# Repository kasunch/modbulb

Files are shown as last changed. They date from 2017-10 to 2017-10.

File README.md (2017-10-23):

# modBulb - A modular light bulb for VLC
modBulb is an open source light bulb with a modular design that can be customized according to application’s requirements.
modBulb allows users to generate baseband signals simply through an MCU or an FPGA where more sophisticated signal processing is required. 
Moreover, modBulb offers the convenience of reprogramming the MCU and FPGA wirelessly to the users. 

modBulb uses an energy efficient switching LED driving circuitry which makes modBulb usable beyond prototyping and research applications.

## Hardware

modBulb hardware consists of three parts:

- Light source i.e. LEDs
- LED driver
- Baseband generator

There are two types of baseband generators:

- MCU baseband generator

  This baseband generator is built with TI's CC3200 SoC which is clocked at 80 MHz.

- FPGA baseband generator

  This baseband generator is built with Microsemi's AGLN060 FPGA which is clocked at 20 MHz.

Following figure shows the two baseband generators (top: FPGA baseband generator, middle MCU baseband generator) and the LED driver. 

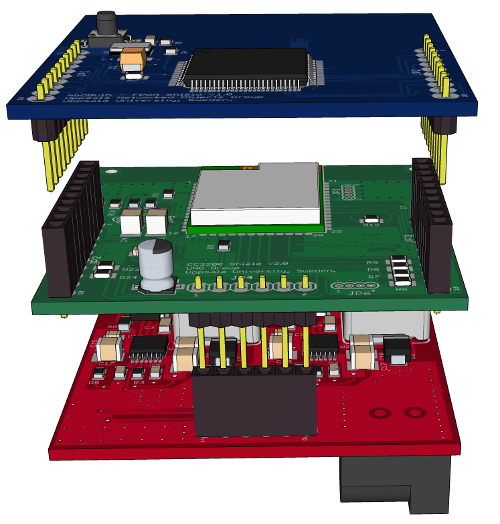
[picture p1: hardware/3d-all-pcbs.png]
PCBs together


Prototype Implementation
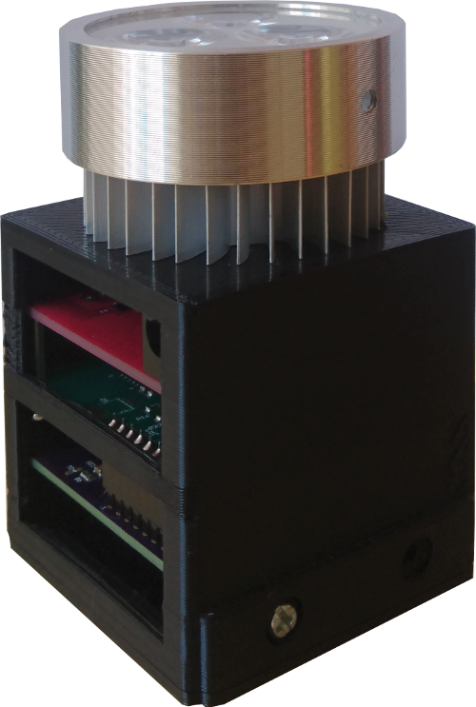
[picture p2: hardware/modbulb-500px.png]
Prototype


## Software

modBulb software undergoes a major restructuring  at the moment. However, the current software can be found in [github.com/modBulb/modBulb](https://github.com/modBulb/modBulb).

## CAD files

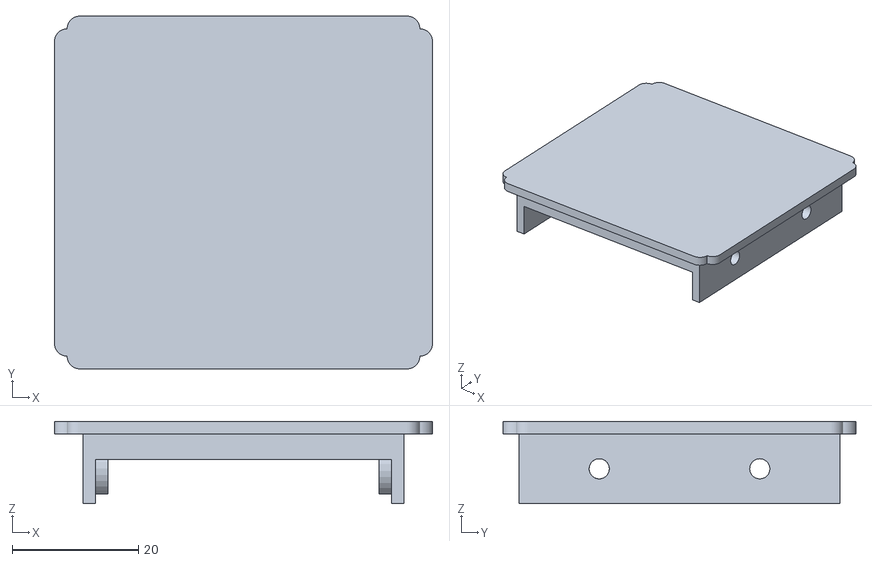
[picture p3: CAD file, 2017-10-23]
hardware/enclosure/enclosure-lid-repaired_netfabb.stl
59.8 x 55.8 x 13.0

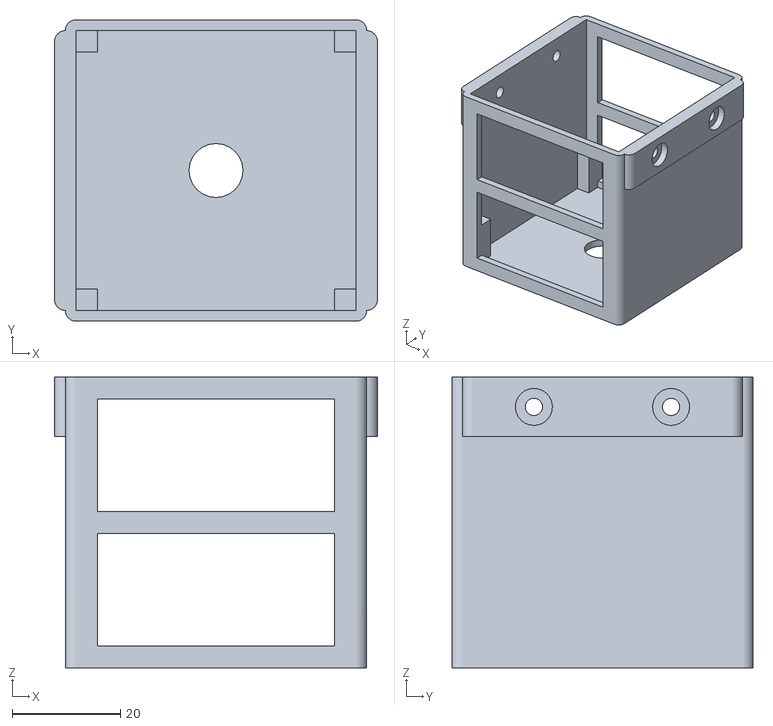
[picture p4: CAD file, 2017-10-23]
hardware/enclosure/enclosure_netfabb.stl
59.8 x 55.8 x 53.8

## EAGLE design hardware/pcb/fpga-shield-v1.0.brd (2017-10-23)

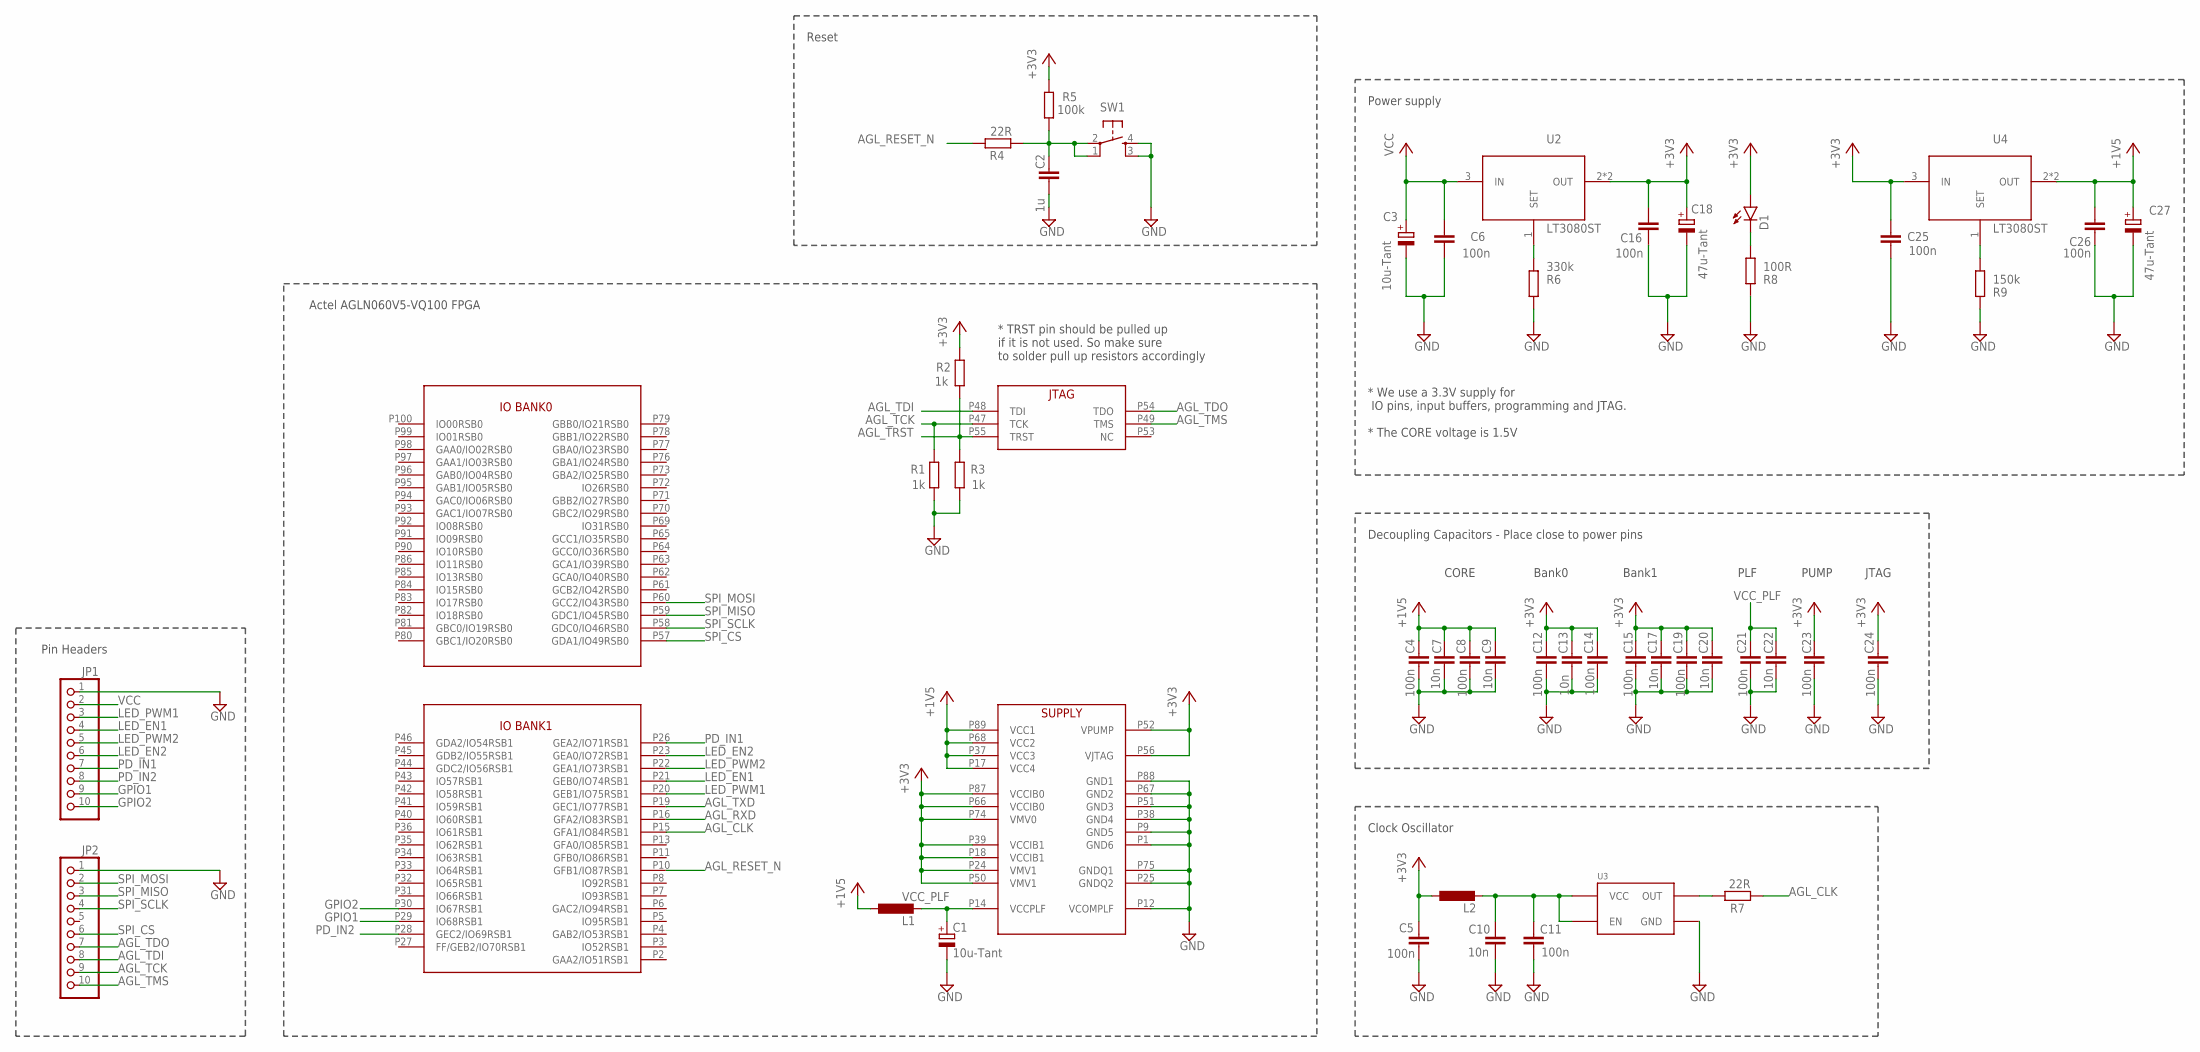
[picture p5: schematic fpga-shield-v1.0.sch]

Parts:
C1, C3: 10u-Tant; CT3528
C2: 1u; C0805
C4, C5, C6, C8, C11, C12, C14, C15, C16, C19, C21, C23, C24, C25, C26: 100n; C0805
C7, C9, C10, C13, C17, C20, C22: 10n; C0805
C18, C27: 47u-Tant; CT3528
D1: LED0603; LED-0603
JP1, JP2: PINHD-1X10; 1X10
L1, L2: L-EUL3216C; L3216C
R1, R2, R3: 1k; R0805
R4, R7: 22R; R0805
R5: 100k; R0805
R6: 330k; R0805
R8: 100R; R0805
R9: 150k; R0805
SW1: 10-XX4X4SMD; BT4X4
U1: AGLN060VQ100; VQ100
U2, U4: LT3080ST; SOT223
U3: ASFL1

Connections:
+1V5: C4.1, C7.1, C8.1, C9.1, C26.1, C27.+, L1.1, U1.P17 (VCC4), U1.P37 (VCC3), U1.P68 (VCC2), U1.P89 (VCC1), U4.2 (OUT), U4.4 (OUT)
+3V3: C5.1, C12.1, C13.1, C14.1, C15.1, C16.1, C17.1, C18.+, C19.1, C20.1, C23.1, C24.1, C25.1, D1.A, L2.1, R2.2, R5.2, U1.P18 (VCCIB1), U1.P24 (VMV1), U1.P39 (VCCIB1), U1.P50 (VMV1), U1.P52 (VPUMP), U1.P56 (VJTAG), U1.P66 (VCCIB0), U1.P74 (VMV0), U1.P87 (VCCIB0), U2.2 (OUT), U2.4 (OUT), U4.3 (IN)
AGL_CLK: R7.2, U1.P15 (GFA1/IO84RSB1)
AGL_RESET_N: R4.2, U1.P10 (GFB1/IO87RSB1)
AGL_RXD: U1.P16 (GFA2/IO83RSB1)
AGL_TCK: JP2.9, R1.2, U1.P47 (TCK)
AGL_TDI: JP2.8, U1.P48 (TDI)
AGL_TDO: JP2.7, U1.P54 (TDO)
AGL_TMS: JP2.10, U1.P49 (TMS)
AGL_TRST: R2.1, R3.2, U1.P55 (TRST)
AGL_TXD: U1.P19 (GEC1/IO77RSB1)
GND: C1.-, C2.2, C3.-, C4.2, C5.2, C6.2, C7.2, C8.2, C9.2, C10.2, C11.2, C12.2, C13.2, C14.2, C15.2, C16.2, C17.2, C18.-, C19.2, C20.2, C21.2, C22.2, C23.2, C24.2, C25.2, C26.2, C27.-, JP1.1, JP2.1, R1.1, R3.1, R6.2, R8.2, R9.2, SW1.3 (S1), SW1.4 (S), U1.P1 (GND6), U1.P9 (GND5), U1.P12 (VCOMPLF), U1.P25 (GNDQ2), U1.P38 (GND4), U1.P51 (GND3), U1.P67 (GND2), U1.P75 (GNDQ1), U1.P88 (GND1), U3.P$2 (GND)
GPIO1: JP1.9, U1.P29 (IO68RSB1)
GPIO2: JP1.10, U1.P30 (IO67RSB1)
LED_EN1: JP1.4, U1.P21 (GEB0/IO74RSB1)
LED_EN2: JP1.6, U1.P23 (GEA0/IO72RSB1)
LED_PWM1: JP1.3, U1.P20 (GEB1/IO75RSB1)
LED_PWM2: JP1.5, U1.P22 (GEA1/IO73RSB1)
unnamed: R7.1, U3.P$3 (OUT)
unnamed: C10.1, C11.1, L2.2, U3.P$1 (EN), U3.P$4 (VCC)
unnamed: D1.C, R8.1
unnamed: R6.1, U2.1 (SET)
unnamed: R9.1, U4.1 (SET)
unnamed: C2.1, R4.1, R5.1, SW1.1, SW1.2
PD_IN1: JP1.7, U1.P26 (GEA2/IO71RSB1)
PD_IN2: JP1.8, U1.P28 (GEC2/IO69RSB1)
SPI_CS: JP2.6, U1.P57 (GDA1/IO49RSB0)
SPI_MISO: JP2.3, U1.P59 (GDC1/IO45RSB0)
SPI_MOSI: JP2.2, U1.P60 (GCC2/IO43RSB0)
SPI_SCLK: JP2.4, U1.P58 (GDC0/IO46RSB0)
VCC: C3.+, C6.1, JP1.2, U2.3 (IN)
VCC_PLF: C1.+, C21.1, C22.1, L1.2, U1.P14 (VCCPLF)

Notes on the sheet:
* We use a 3.3V supply for IO pins, input buffers, programming and JTAG. * The CORE voltage is 1.5V
Decoupling Capacitors - Place close to power pins
CORE
Bank0
Bank1
PLF
PUMP
JTAG
* TRST pin should be pulled up if it is not used. So make sure to solder pull up resistors accordingly
Clock Oscillator
Power supply
Reset
Actel AGLN060V5-VQ100 FPGA
Pin Headers

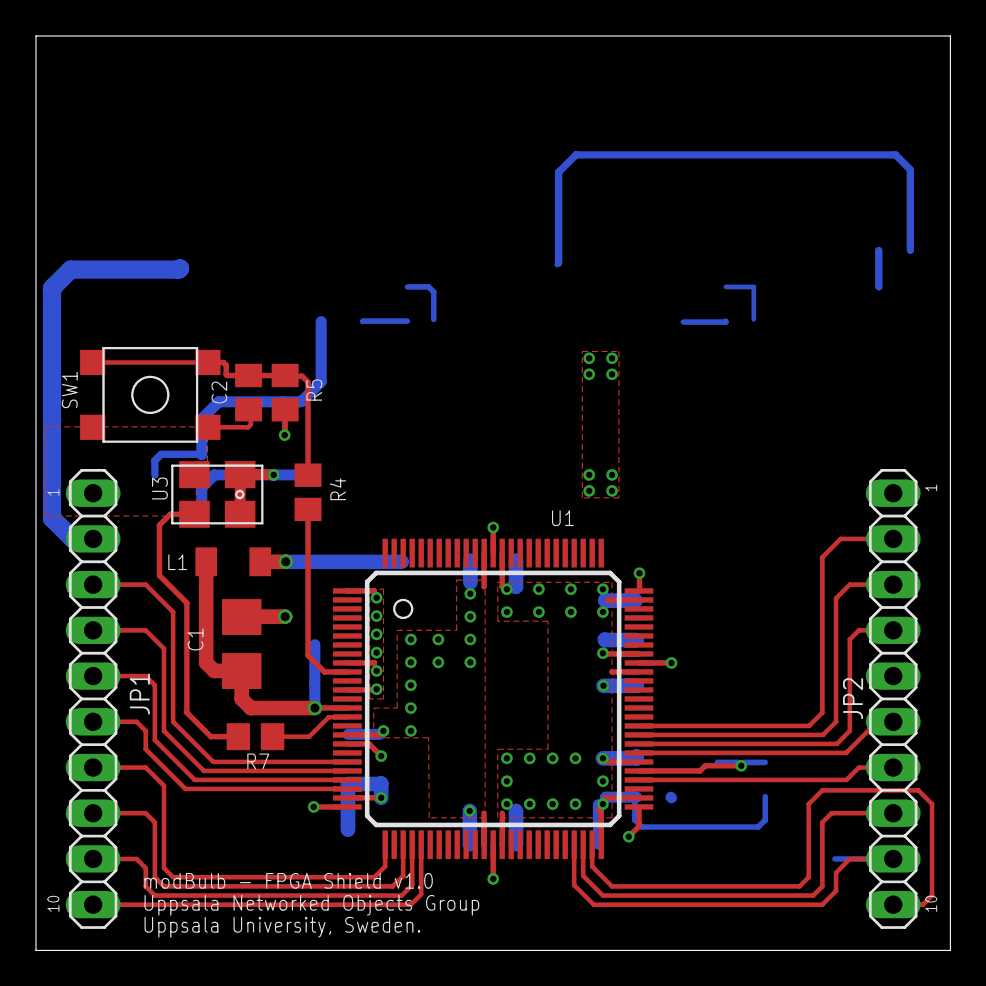
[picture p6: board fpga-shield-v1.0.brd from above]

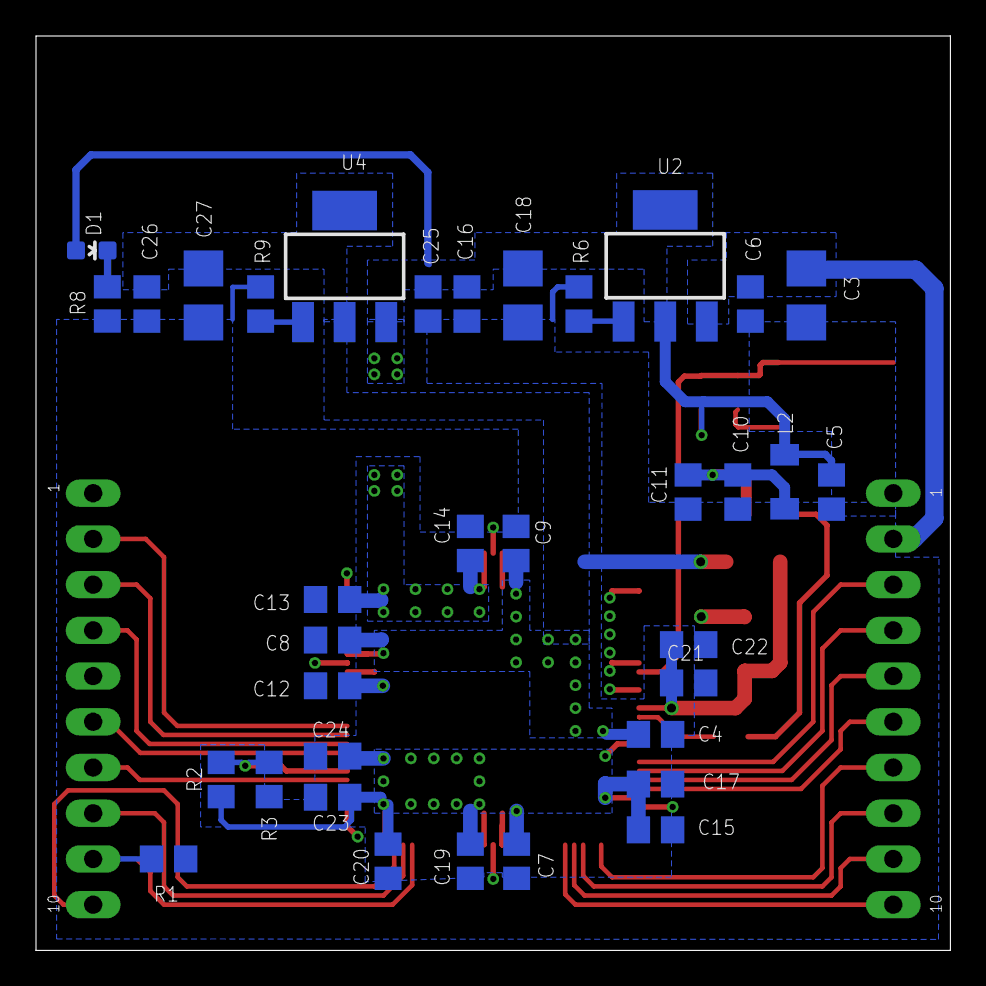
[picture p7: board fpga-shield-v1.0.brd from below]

Board: 2 copper layers, 50.8 x 50.8 mm, 46 parts (35 on the bottom side), 30 nets.

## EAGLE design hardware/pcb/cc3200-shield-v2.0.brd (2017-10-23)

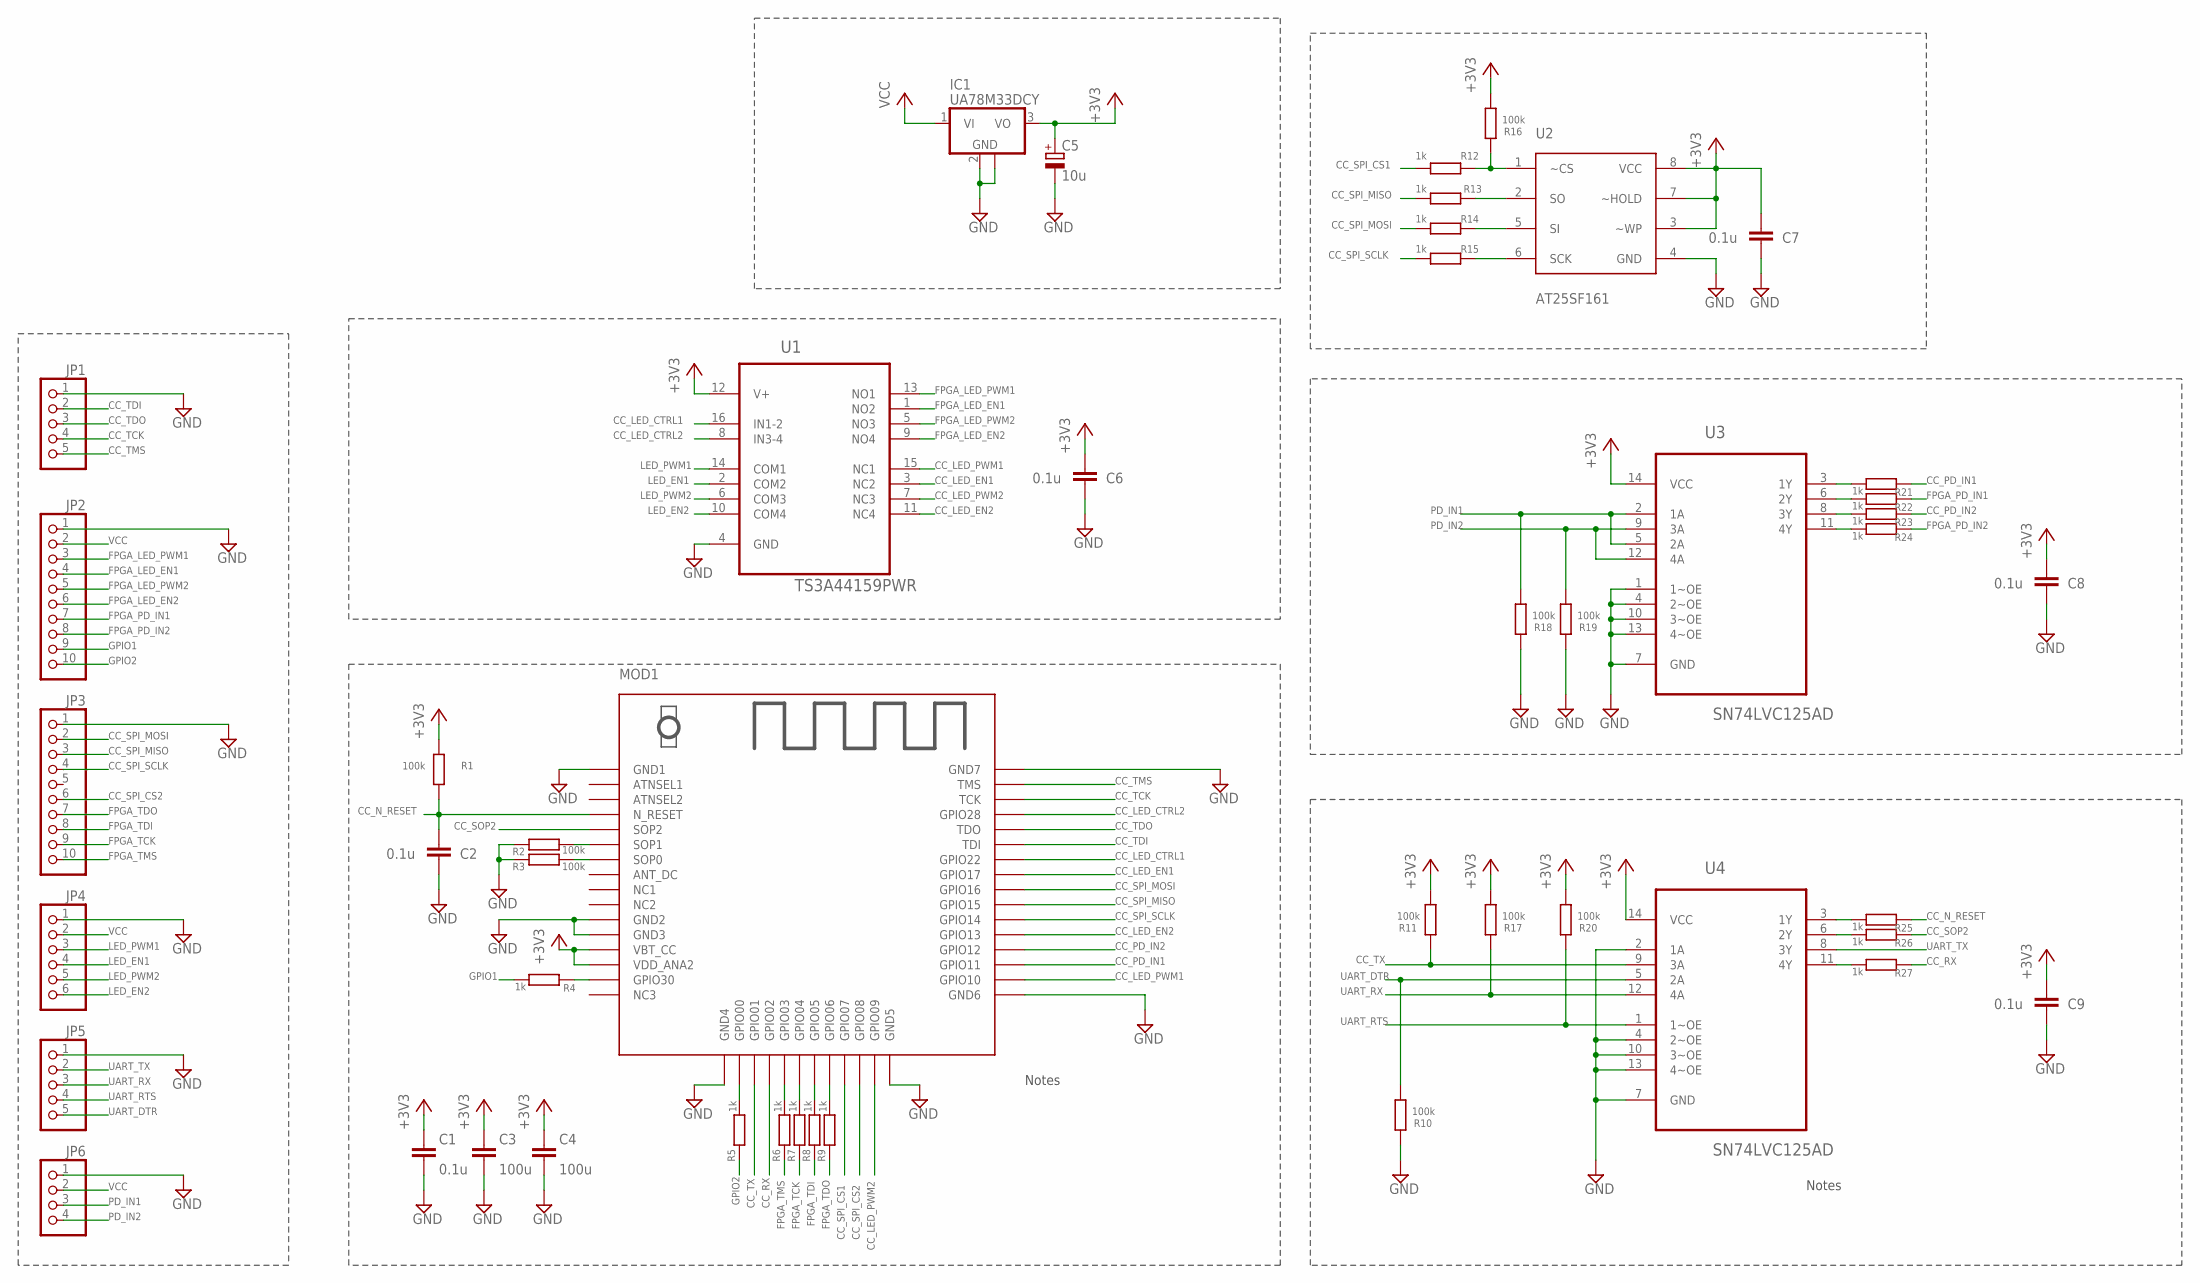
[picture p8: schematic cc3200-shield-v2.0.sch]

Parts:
C1, C2, C6, C7, C8, C9: 0.1u; C0805
C3, C4: 100u; C1210
C5: 10u; 153CLV-0405
IC1: UA78M33DCY; SOT223
JP1, JP5: PINHD-1X51X05-1.27MM; 1X05-1.27MM
JP2, JP3: PINHD-1X10; 1X10
JP4: PINHD-1X6; 1X06
JP6: PINHD-1X41.27MM; 1X04-1.27MM
MOD1: USR-C322
R1, R2, R3, R10, R11, R16, R17, R18, R19, R20: 100k; R0805
R4, R5, R6, R7, R8, R9, R12, R13, R14, R15, R21, R22, R23, R24, R25, R26, R27: 1k; R0805
U1: TS3A44159PWR; SOP65P640X120-16N
U2: AT25SF161; SO08
U3, U4: SN74LVC125AD; SOIC127P600X175-14N

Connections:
+3V3: C1.1, C3.1, C4.1, C5.+, C6.1, C7.1, C8.1, C9.1, IC1.3 (VO), MOD1.VBT_CC, MOD1.VDD_ANT (VDD_ANA2), R1.2, R11.2, R16.2, R17.2, R20.2, U1.12 (V+), U2.3 (~WP), U2.7 (~HOLD), U2.8 (VCC), U3.14 (VCC), U4.14 (VCC)
CC_LED_CTRL1: MOD1.GPIO22, U1.16 (IN1-2)
CC_LED_CTRL2: MOD1.GPIO28, U1.8 (IN3-4)
CC_LED_EN1: MOD1.GPIO17, U1.3 (NC2)
CC_LED_EN2: MOD1.GPIO13, U1.11 (NC4)
CC_LED_PWM1: MOD1.GPIO10, U1.15 (NC1)
CC_LED_PWM2: MOD1.GPIO09, U1.7 (NC3)
CC_N_RESET: C2.1, MOD1.N_RESET, R1.1, R25.1
CC_PD_IN1: MOD1.GPIO11, R21.1
CC_PD_IN2: MOD1.GPIO12, R23.1
CC_RX: MOD1.GPIO02, R27.1
CC_SOP2: MOD1.SOP2, R26.1
CC_SPI_CS1: MOD1.GPIO07, R12.2
CC_SPI_CS2: JP3.6, MOD1.GPIO08
CC_SPI_MISO: JP3.3, MOD1.SPI_MISO/GPIO15 (GPIO15), R13.2
CC_SPI_MOSI: JP3.2, MOD1.GPIO16, R14.2
CC_SPI_SCLK: JP3.4, MOD1.GPIO14, R15.2
CC_TCK: JP1.4, MOD1.TCK
CC_TDI: JP1.2, MOD1.TDI
CC_TDO: JP1.3, MOD1.TDO
CC_TMS: JP1.5, MOD1.TMS
CC_TX: MOD1.GPIO01, R11.1, U4.9 (3A)
FPGA_LED_EN1: JP2.4, U1.1 (NO2)
FPGA_LED_EN2: JP2.6, U1.9 (NO4)
FPGA_LED_PWM1: JP2.3, U1.13 (NO1)
FPGA_LED_PWM2: JP2.5, U1.5 (NO3)
FPGA_PD_IN1: JP2.7, R22.1
FPGA_PD_IN2: JP2.8, R24.1
FPGA_TCK: JP3.9, R7.1
FPGA_TDI: JP3.8, R8.1
FPGA_TDO: JP3.7, R9.1
FPGA_TMS: JP3.10, R6.1
GND: C1.2, C2.2, C3.2, C4.2, C5.-, C6.2, C7.2, C8.2, C9.2, IC1.2 (GND), IC1.4 (GND), JP1.1, JP2.1, JP3.1, JP4.1, JP5.1, JP6.1, MOD1.GND1, MOD1.GND2, MOD1.GND3, MOD1.GND4, MOD1.GND5, MOD1.GND6, MOD1.GND7, R2.1, R3.1, R10.1, R18.1, R19.1, U1.4 (GND), U2.4 (GND), U3.1 (1~OE), U3.4 (2~OE), U3.7 (GND), U3.10 (3~OE), U3.13 (4~OE), U4.2 (1A), U4.4 (2~OE), U4.7 (GND), U4.10 (3~OE), U4.13 (4~OE)
GPIO1: JP2.9, R4.2
GPIO2: JP2.10, R5.1
LED_EN1: JP4.4, U1.2 (COM2)
LED_EN2: JP4.6, U1.10 (COM4)
LED_PWM1: JP4.3, U1.14 (COM1)
LED_PWM2: JP4.5, U1.6 (COM3)
unnamed: MOD1.SOP1, R2.2
unnamed: MOD1.SOP0, R3.2
unnamed: MOD1.GPIO00, R5.2
unnamed: MOD1.GPIO30, R4.1
unnamed: MOD1.GPIO03, R6.2
unnamed: MOD1.GPIO04, R7.2
unnamed: MOD1.GPIO05, R8.2
unnamed: MOD1.GPIO06, R9.2
unnamed: R25.2, U4.3 (1Y)
unnamed: R26.2, U4.6 (2Y)
unnamed: R27.2, U4.11 (4Y)
unnamed: R12.1, R16.1, U2.1 (~CS)
unnamed: R21.2, U3.3 (1Y)
unnamed: R22.2, U3.6 (2Y)
unnamed: R23.2, U3.8 (3Y)
unnamed: R24.2, U3.11 (4Y)
unnamed: R13.1, U2.2 (SO)
unnamed: R14.1, U2.5 (SI)
unnamed: R15.1, U2.6 (SCK)
PD_IN1: JP6.3, R18.2, U3.2 (1A), U3.5 (2A)
PD_IN2: JP6.4, R19.2, U3.9 (3A), U3.12 (4A)
UART_DTR: JP5.5, R10.2, U4.5 (2A)
UART_RTS: JP5.4, R20.1, U4.1 (1~OE)
UART_RX: JP5.3, R17.1, U4.12 (4A)
UART_TX: JP5.2, U4.8 (3Y)
VCC: IC1.1 (VI), JP2.2, JP4.2, JP6.2

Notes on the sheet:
Notes

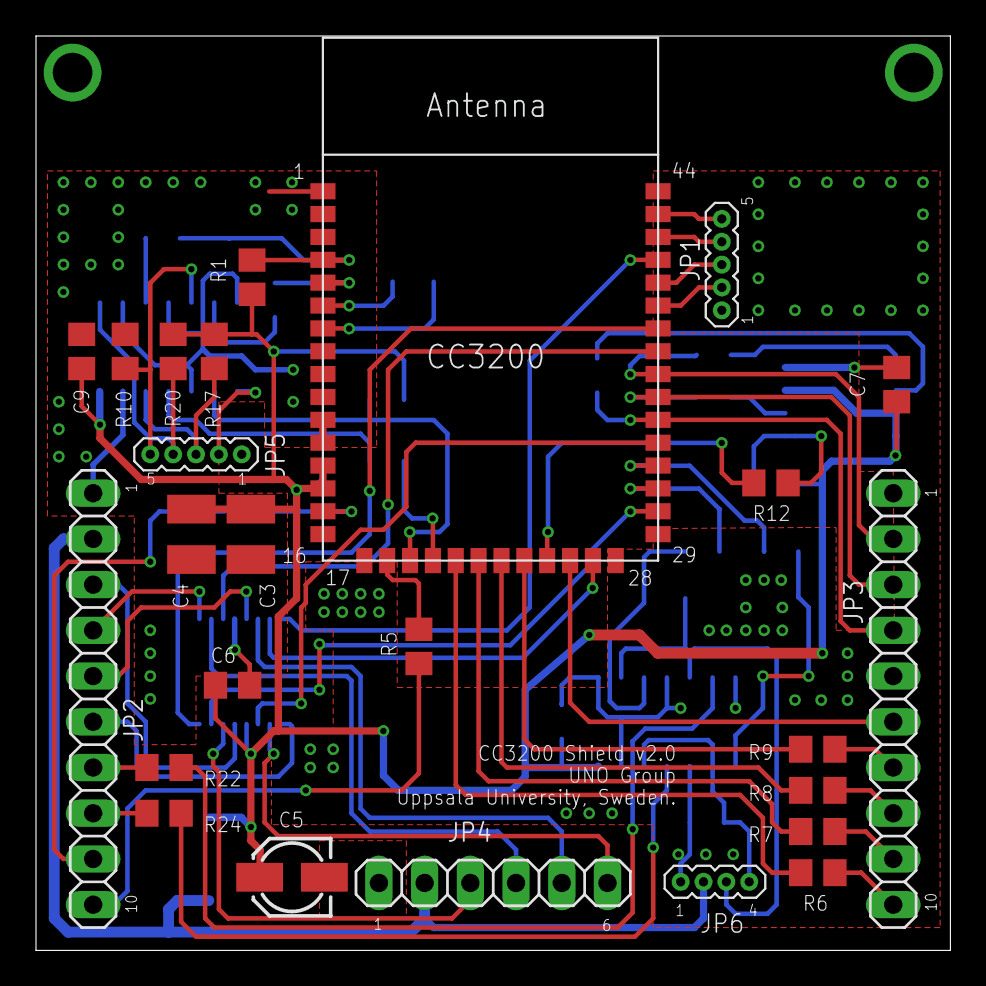
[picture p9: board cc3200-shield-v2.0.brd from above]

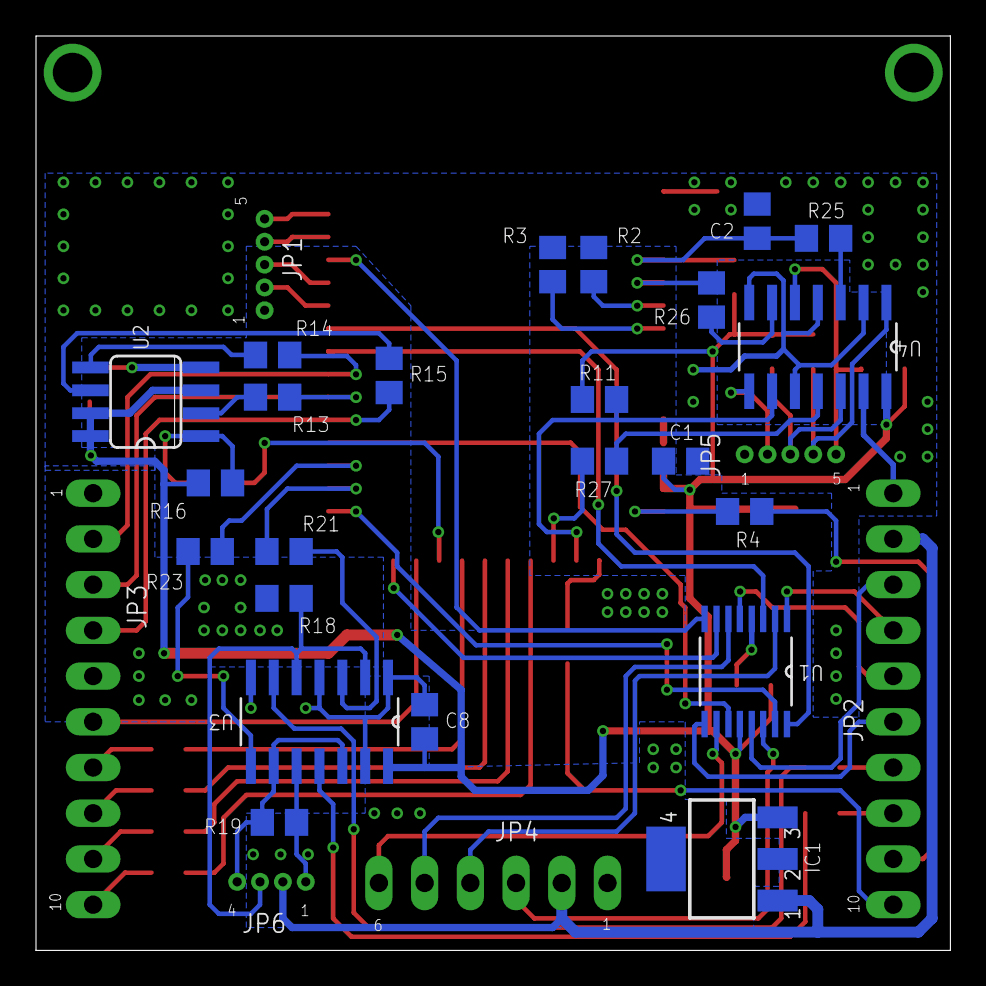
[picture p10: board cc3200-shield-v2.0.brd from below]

Board: 2 copper layers, 50.8 x 50.8 mm, 48 parts (23 on the bottom side), 65 nets.

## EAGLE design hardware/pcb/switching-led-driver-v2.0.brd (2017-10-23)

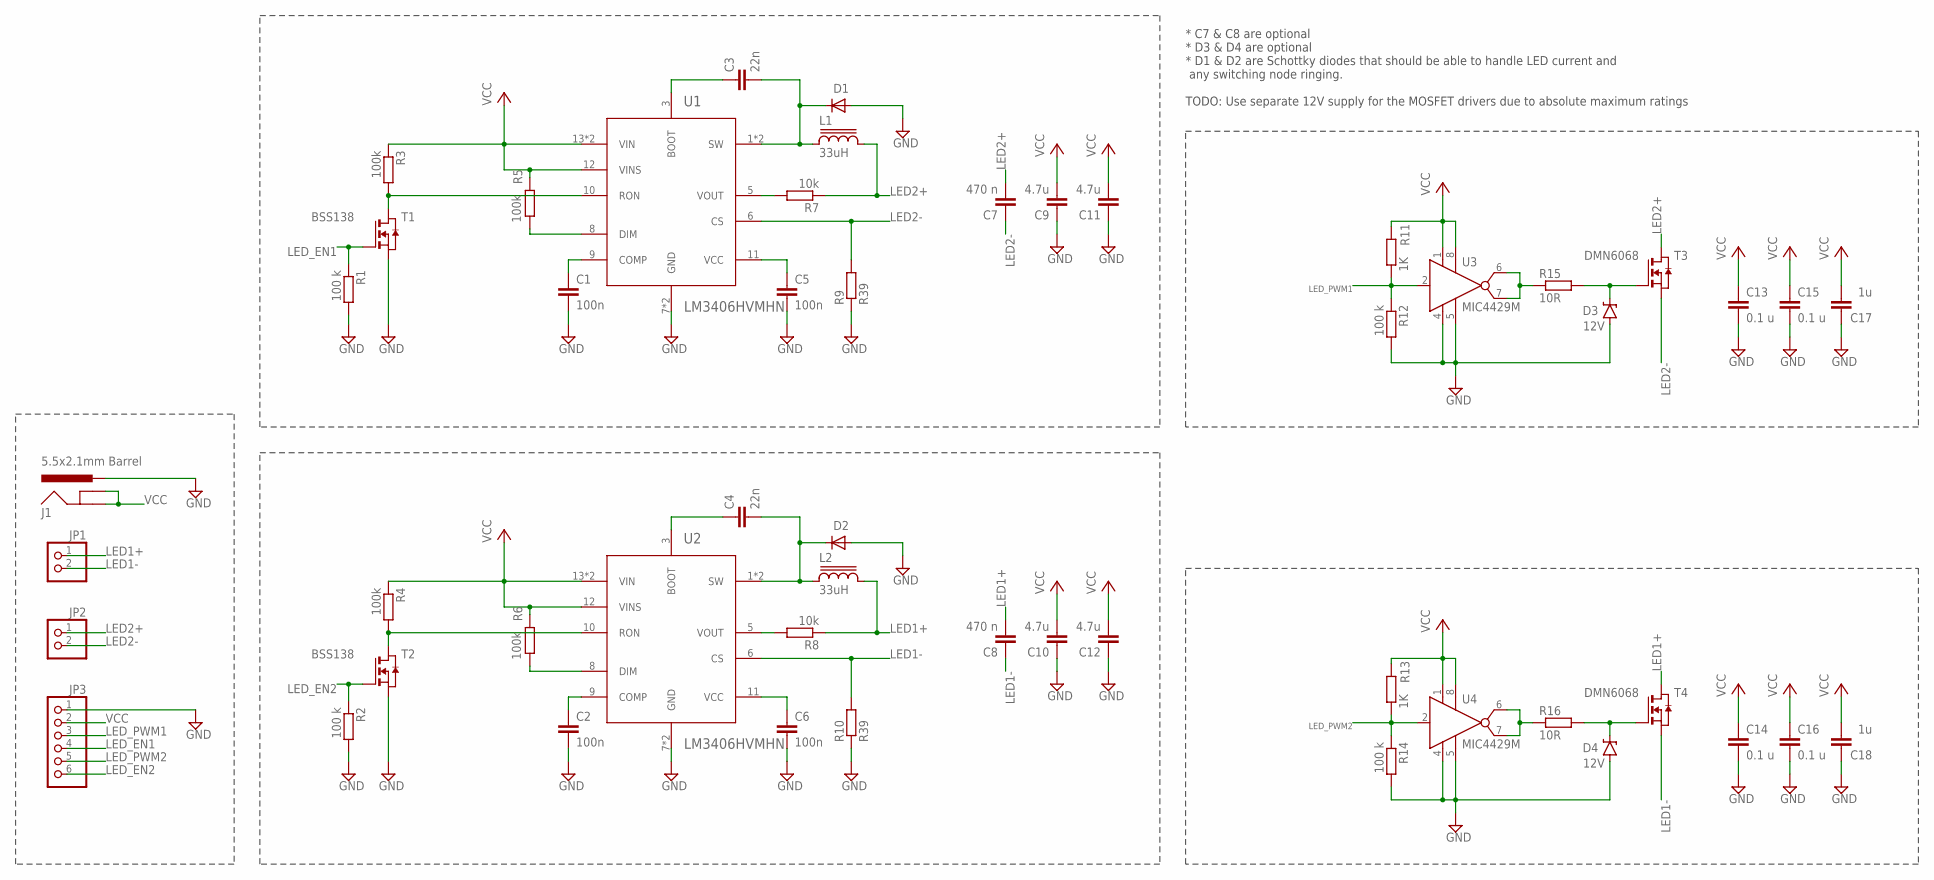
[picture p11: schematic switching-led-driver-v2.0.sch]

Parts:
C1, C2, C5, C6: 100n; C0805
C3, C4: 22n; C1206
C7, C8: 470 n; C1206
C9, C10, C11, C12: 4.7u; C1210
C13, C14, C15, C16: 0.1 u; C0805
C17, C18: 1u; C1210
D1, D2: 12V; DO-214AC
D3, D4: 12V; SOD-123
J1: 5.5x2.1mm Barrel; POWER_JACK_SMD
JP1, JP2: PINHD-1X2; 1X02
JP3: PINHD-1X6; 1X06
L1, L2: 33uH; SRR1260
R1, R2, R12, R14: 100 k; R0805
R3, R4, R5, R6: 100k; R0805
R7, R8: 10k; R0805
R9, R10: R39; R1206
R11, R13: 1K; R0805
R15, R16: 10R; R0805
T1, T2: BSS138; SOT-23
T3, T4: DMN6068; SOT223
U1, U2: LM3406HVMHN; HTSSOP-14-NN
U3, U4: MIC4429M; SO08

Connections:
GND: C1.2, C2.2, C5.2, C6.2, C9.1, C10.1, C11.1, C12.1, C13.2, C14.2, C15.2, C16.2, C17.1, C18.1, D1.A, D2.A, D3.A, D4.A, J1.VIN0 (PWR), JP3.1, R1.2, R2.2, R9.1, R10.1, R12.2, R14.2, T1.2 (S), T2.2 (S), U1.7 (GND), U1.15 (GND), U2.7 (GND), U2.15 (GND), U3.4 (GND1), U3.5 (GND2), U4.4 (GND1), U4.5 (GND2)
LED1+: C8.2, JP1.1, L2.2, R8.1, T4.2 (D), T4.4 (D)
LED1-: C8.1, JP1.2, R10.2, T4.3 (S), U2.6 (CS)
LED2+: C7.2, JP2.1, L1.2, R7.1, T3.2 (D), T3.4 (D)
LED2-: C7.1, JP2.2, R9.2, T3.3 (S), U1.6 (CS)
LED_EN1: JP3.4, R1.1, T1.3 (G)
LED_EN2: JP3.6, R2.1, T2.3 (G)
LED_PWM1: JP3.3, R11.1, R12.1, U3.2 (IN)
LED_PWM2: JP3.5, R13.1, R14.1, U4.2 (IN)
unnamed: R4.2, T2.1 (D), U2.10 (RON)
unnamed: C2.1, U2.9 (COMP)
unnamed: C6.1, U2.11 (VCC)
unnamed: R16.1, U4.6 (OUT1), U4.7 (OUT2)
unnamed: R8.2, U2.5 (VOUT)
unnamed: D3.C, R15.2, T3.1 (G)
unnamed: D4.C, R16.2, T4.1 (G)
unnamed: R3.2, T1.1 (D), U1.10 (RON)
unnamed: C1.1, U1.9 (COMP)
unnamed: C5.1, U1.11 (VCC)
unnamed: C3.1, U1.3 (BOOT)
unnamed: C4.1, U2.3 (BOOT)
unnamed: R7.2, U1.5 (VOUT)
unnamed: R15.1, U3.6 (OUT1), U3.7 (OUT2)
PWM_IN_INT: R6.1, U2.8 (DIM)
PWM_IN_INT1: R5.1, U1.8 (DIM)
SW: C4.2, D2.C, L2.1, U2.1 (SW), U2.2 (SW)
SW1: C3.2, D1.C, L1.1, U1.1 (SW), U1.2 (SW)
VCC: C9.2, C10.2, C11.2, C12.2, C13.1, C14.1, C15.1, C16.1, C17.2, C18.2, J1.GND (GNDBREAK), J1.P$4 (GND), JP3.2, R3.1, R4.1, R5.2, R6.2, R11.2, R13.2, U1.12 (VINS), U1.13 (VIN), U1.14 (VIN), U2.12 (VINS), U2.13 (VIN), U2.14 (VIN), U3.1 (VS1), U3.8 (VS2), U4.1 (VS1), U4.8 (VS2)

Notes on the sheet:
* C7 & C8 are optional * D3 & D4 are optional * D1 & D2 are Schottky diodes that should be able to handle LED current and any switching node ringing. TODO: Use separate 12V supply for the MOSFET drivers due to absolute maximum ratings

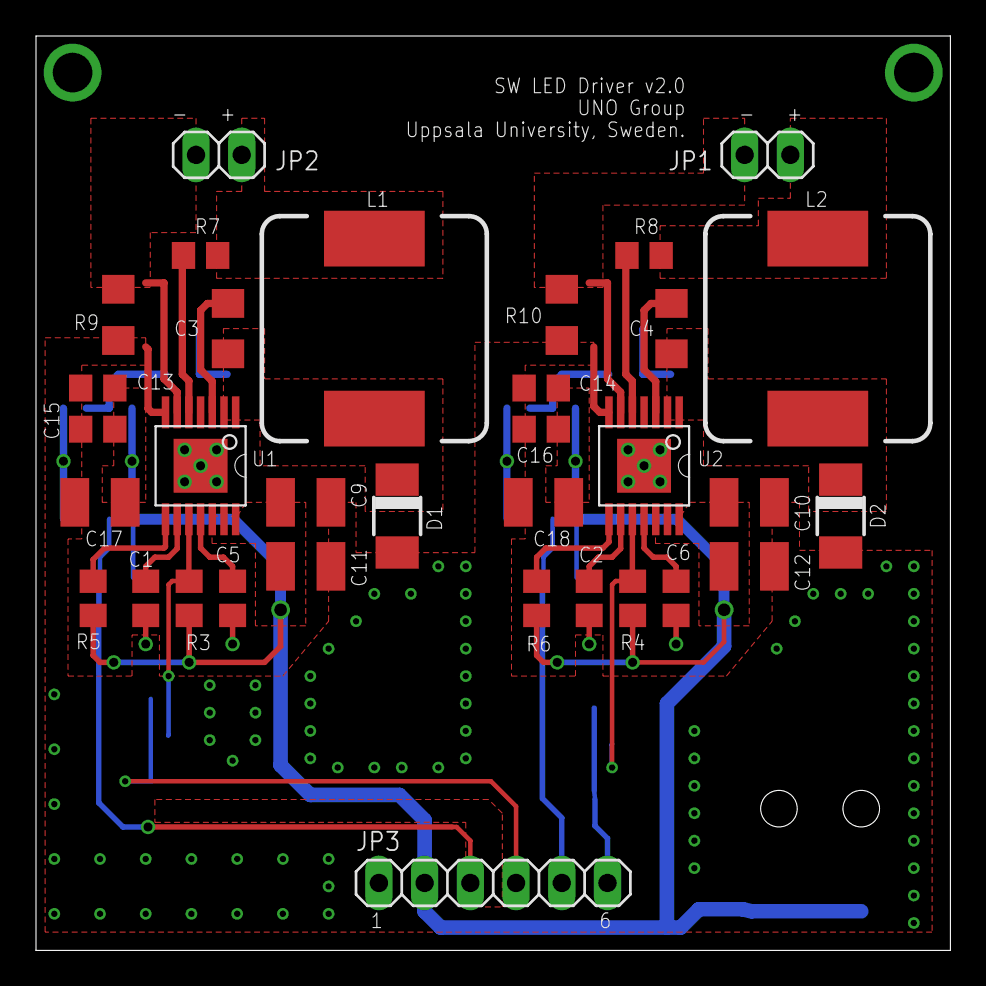
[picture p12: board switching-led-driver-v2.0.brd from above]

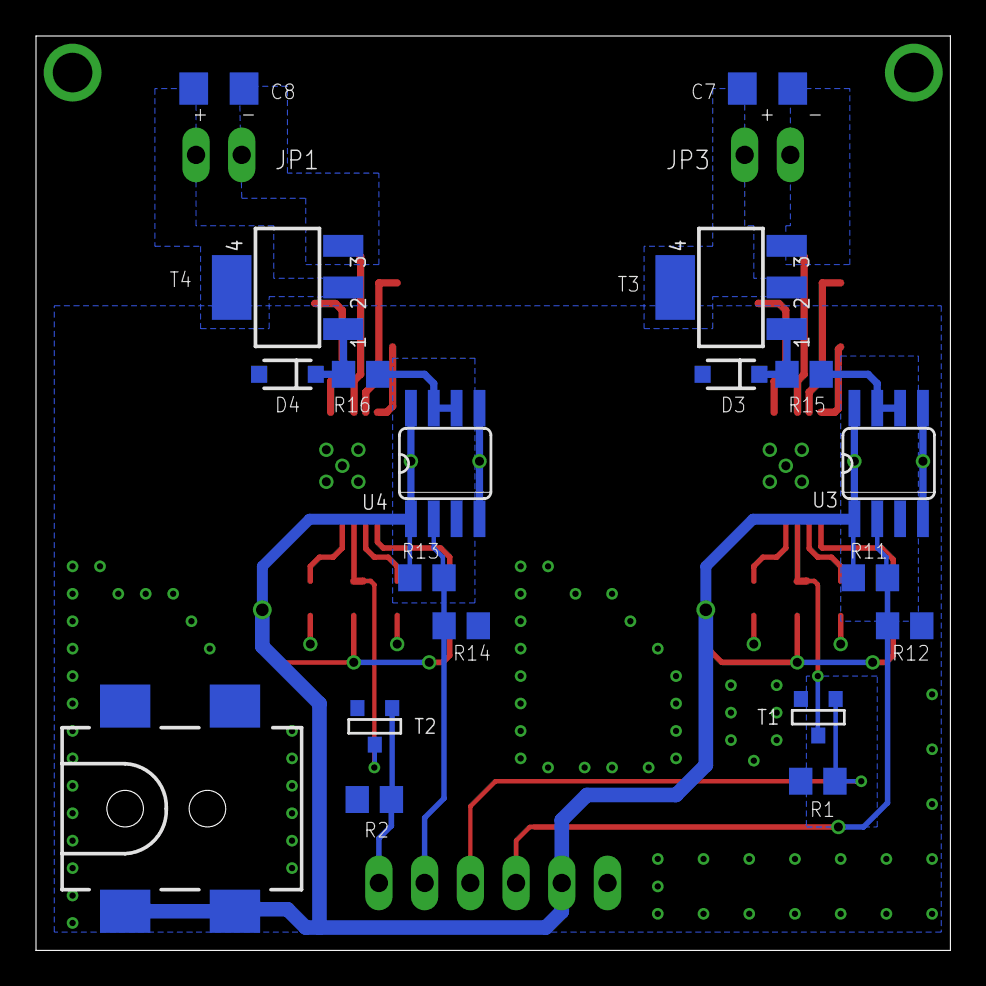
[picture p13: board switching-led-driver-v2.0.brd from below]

Board: 2 copper layers, 50.8 x 50.8 mm, 52 parts (19 on the bottom side), 28 nets.

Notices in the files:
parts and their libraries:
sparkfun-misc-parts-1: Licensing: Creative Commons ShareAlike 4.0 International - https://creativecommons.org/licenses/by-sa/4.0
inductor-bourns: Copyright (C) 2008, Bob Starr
